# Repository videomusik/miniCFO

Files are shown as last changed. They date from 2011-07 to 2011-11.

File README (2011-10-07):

files for the miniCFO, the little brother to the CHEAP, FAT and OPEN project
===========================================================================
more info: http://8bitklubben.dk/project/CFO/2011/06/minicfo-at-roskilde-festival/
===========================================================================
in this repository you will find Arduino code to program the miniCFO synth (Arduino folder) and CAD files for the hardware design (Eagle folder). At the time being the version of the hardware design is the one made for a synthesizer workshop at Roskilde Festival 2011. A more generic design will be uploaded shortly.

sound code + hardware design in this project is based on the original CFO by Jacob Sikker Remin (https://github.com/jsr606/CFO) which is again based on the arduino synthesizer kit by critter and guittari (http://www.critterandguitari.com/content/arduino-synthesizer-kit)

PLEASE NOTE:
this is a work in progress: we encourage you to optimize/modify the hardware design and tweak the code! 

--- enjoy
          _____                    _____                   _______         
         /\    \                  /\    \                 /::\    \        
        /::\    \                /::\    \               /::::\    \       
       /::::\    \              /::::\    \             /::::::\    \      
      /::::::\    \            /::::::\    \           /::::::::\    \     
     /:::/\:::\    \          /:::/\:::\    \         /:::/~~\:::\    \    
    /:::/  \:::\    \        /:::/__\:::\    \       /:::/    \:::\    \   
   /:::/    \:::\    \      /::::\   \:::\    \     /:::/    / \:::\    \  
  /:::/    / \:::\    \    /::::::\   \:::\    \   /:::/____/   \:::\____\ 
 /:::/    /   \:::\    \  /:::/\:::\   \:::\    \ |:::|    |     |:::|    |
/:::/____/     \:::\____\/:::/  \:::\   \:::\____\|:::|____|     |:::|    |
\:::\    \      \::/    /\::/    \:::\   \::/    / \:::\    \   /:::/    / 
 \:::\    \      \/____/  \/____/ \:::\   \/____/   \:::\    \ /:::/    /  
  \:::\    \                       \:::\    \        \:::\    /:::/    /   
   \:::\    \                       \:::\____\        \:::\__/:::/    /    
    \:::\    \                       \::/    /         \::::::::/    /     
     \:::\    \                       \/____/           \::::::/    /      
      \:::\    \                                         \::::/    /       
       \:::\____\                                         \::/____/        
        \::/    /                                          ~~              
         \/____/

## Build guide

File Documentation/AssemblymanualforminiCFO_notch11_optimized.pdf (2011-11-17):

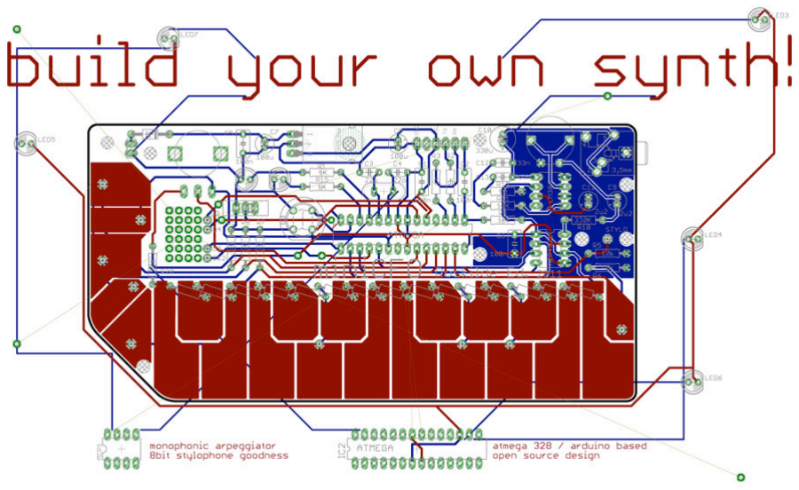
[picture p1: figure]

miniCFO assembly instructions ver1.1 ---- NOTCH11 workshop sept. 22nd 2011 more info: http://8bitklubben.dk/project/CFO/

0) This is the board when you get it. Check that all the components are in the bag!

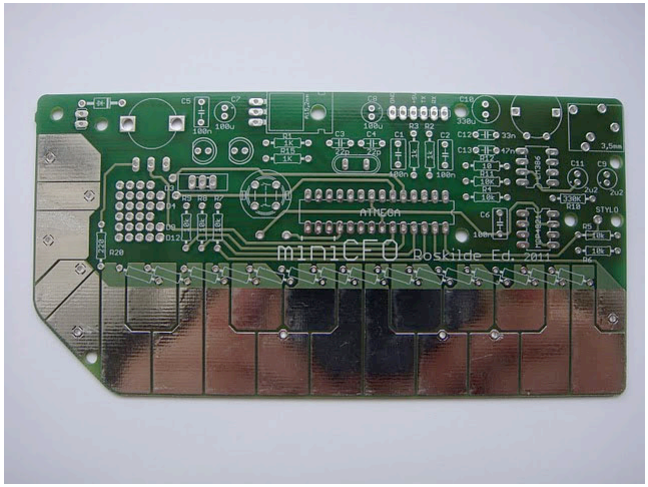
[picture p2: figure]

1) Solder the sixteen 220

Ω resistors near the Stylophone keys. Remember the last one on the far left (R20 that has written “220” in it)

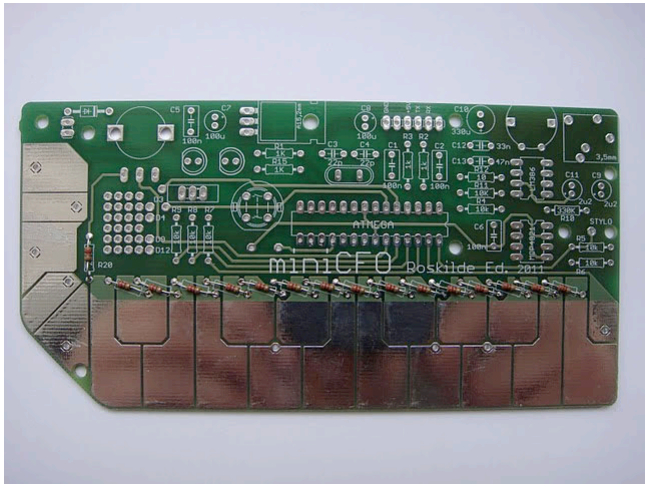
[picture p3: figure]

It can be easier to keep the resistors (and all following components) in place if you bend the legs on the backside of the board, before soldering. Just make sure not to get the legs too close to other soldering points. Snip o

ff the rest of the leg with a cutter when

finished
soldering. All soldering is on the backside, just in case you were in doubt :)

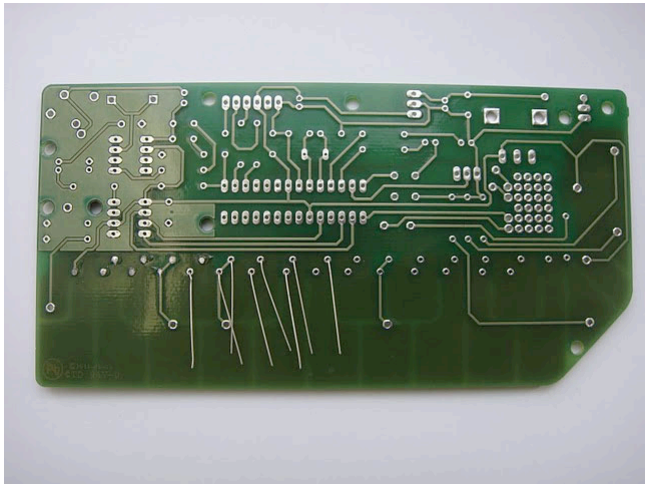
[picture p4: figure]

2) Solder the seven 10K

Ω resistors (R4, R5, R6, R7, R8, R9 and R11)

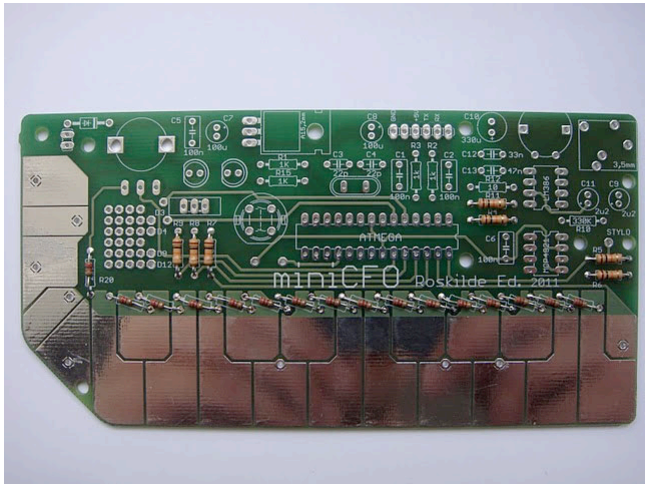
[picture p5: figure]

3) solder the four 1K

Ω resistors (R1, R15, R2 and R3)

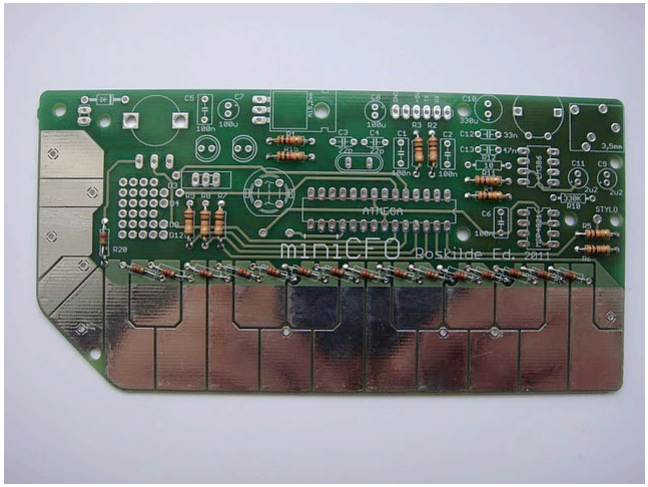
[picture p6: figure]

4) solder the 10

Ω and the 330K

Ω resistors (R12 and R10 respectively)

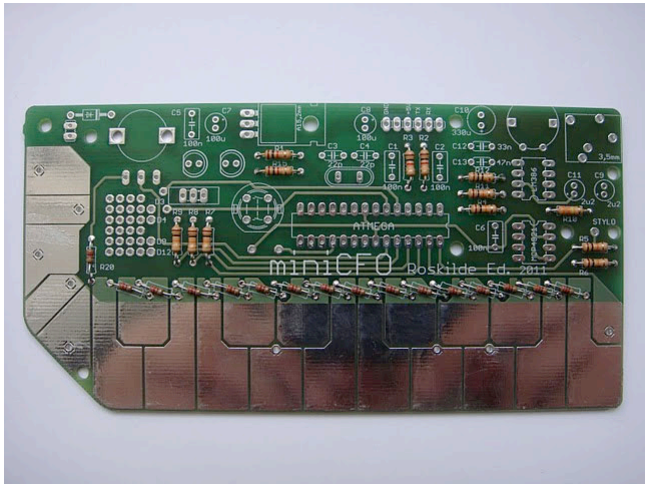
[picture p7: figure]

5) Solder the two 8 pin (MCP4921 and LM386) and the 28 pin (ATMEGA) IC sockets. Make sure that the little groove in one end of each socket lines up with the groove on the silkscreen (the drawings and text on the circuit board). Be aware that the the two 8 pin sockets have their groove pointing towards each other. We use these to help us position the microchips in the right direction later on.

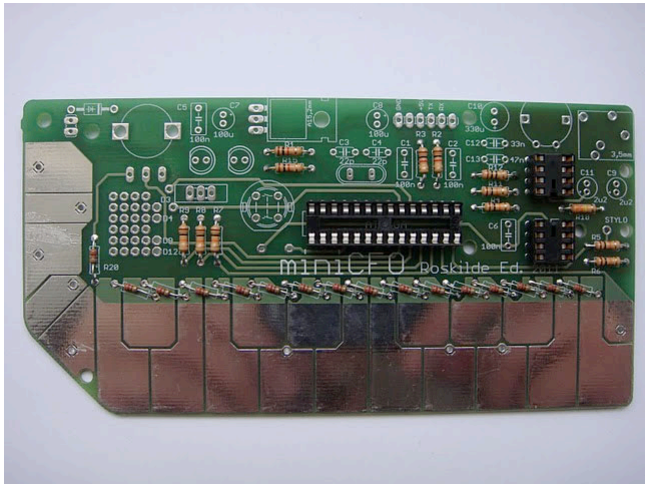
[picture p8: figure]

6) Solder the oscillator. It doesn’t have a direction, but it’s nice if the text

fits with all the rest :)

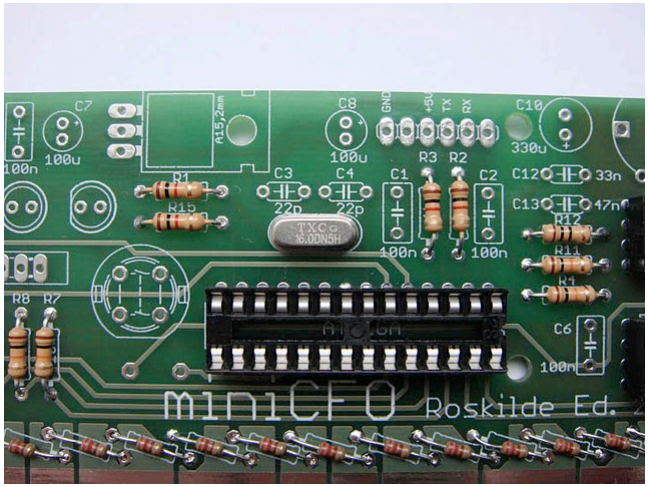
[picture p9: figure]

7) Solder the 6 pin, angled male header.

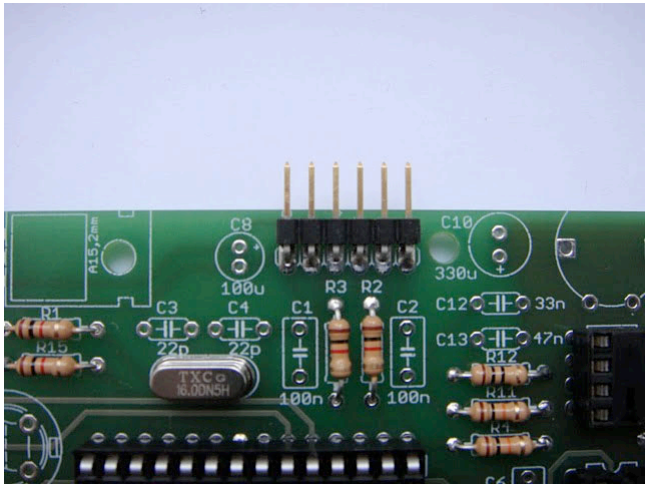
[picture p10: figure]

8) Solder the diode (1N4001). Watch the direction, make sure the white/grey end of the diode is to the right, where there is a white line on the silkscreen.

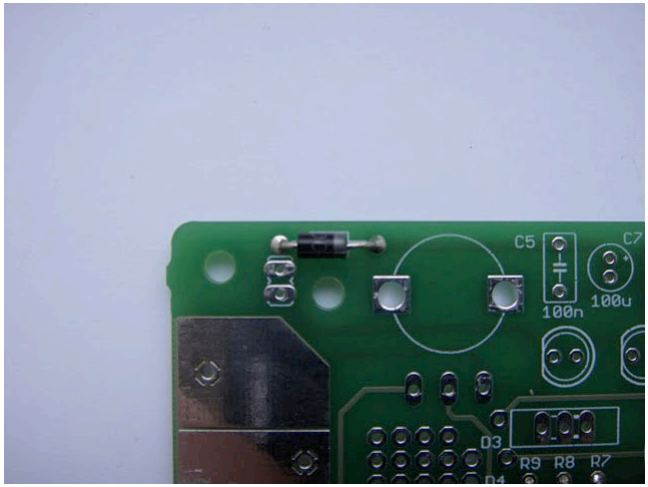
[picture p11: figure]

9) Solder the two 18pF capacitors (C3 and C4) above the oscillator. By a mistake there is written “22p” on the silkscreen, although the capacitors are 18pF.

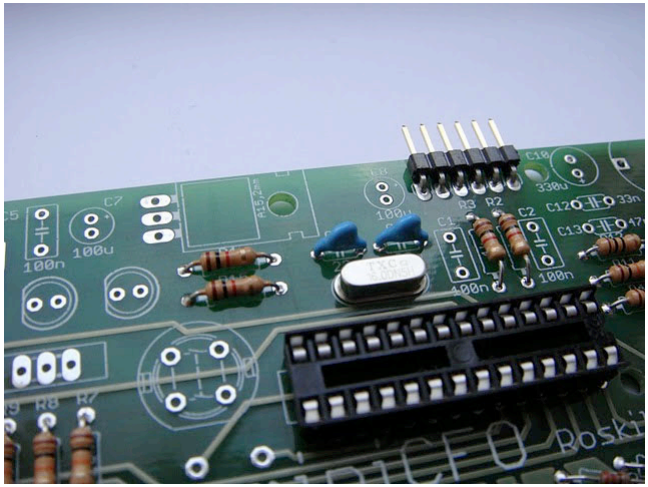
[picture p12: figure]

10) Solder the 33nF and 47nF capacitors (C12 and C13). The 47nF capacitor (C13) is the red one - you can’t miss it. The 33nF capacitor (C12) looks almost identical to the 100nF capacitors we will use in the next step. They are the same blue colour and have the same size. You should be able make out a small “33nJ63” on the proper 33nF one here, and a small “u1K63” on the 100nF ones.

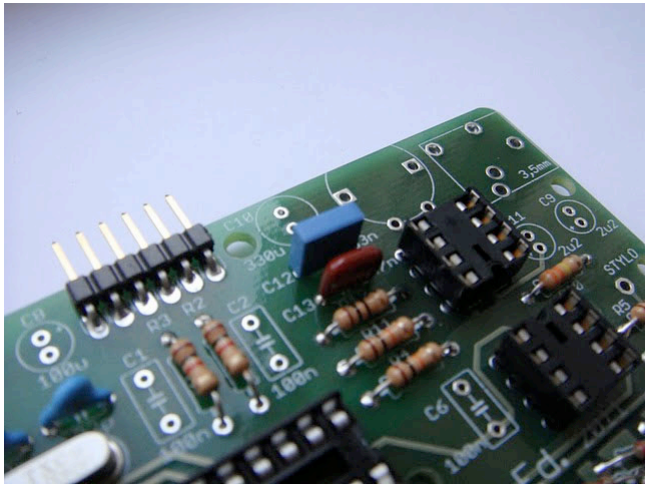
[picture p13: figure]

11) Solder the four 100nF capacitors (C1, C2, C5 and C6). As stated above, they are the blue ones that have a little “u1K63” written on them.

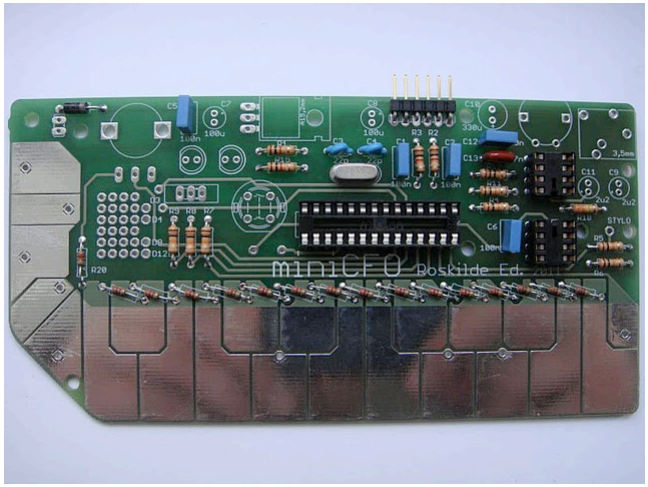
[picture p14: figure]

12) Solder the thumbwheel.

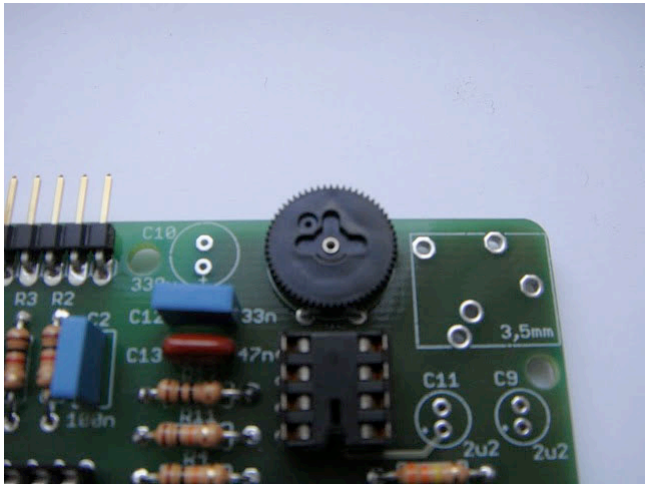
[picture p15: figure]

13) Solder the two LEDs. Watch the direction, make sure the short leg (the negative terminal) is facing left. You can also see it by the slightly

flattened side on the LED. This should be aligned with the

flat side on the silkscreen.

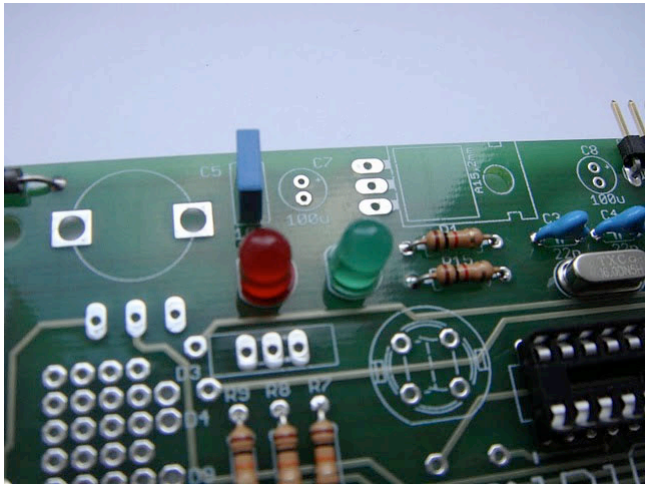
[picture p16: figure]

14) The next few steps are all on the same photo. First Solder the button (the big green thing). Watch the direction, there is a slightly flattened side on it (a little like the LED) which should be aligned with the

flat side on the silkscreen, facing down towards the “keyboard”.
15) Then solder the slider switch (the little black plastic thingy with the tip that slides from side to side :D). No special direction.
16) Lastly solder the 5V regulator. It’s the black thing with three legs and a metal top with a whole in it. Make sure it’s positioned like the photo.

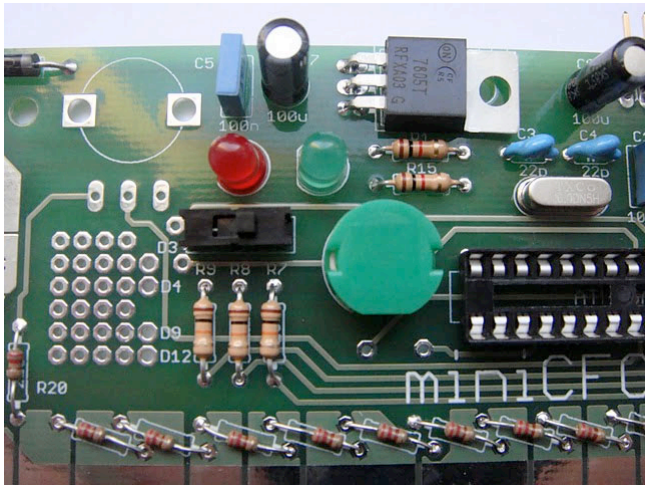
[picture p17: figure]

17) Solder the the electrolytic capacitors: two 2.2µF (C9 and C11), two 100µF (C7 and C8) and one 330µF (C10). Watch the direction, make sure the white line on each capacitor is facing AWAY from the little “+” (plus) on the silkscreen. That means the two 2.2µF capacitors (C9 and C11) and the 330µF (C10) are facing the white line upwards, AWAY from the “keyboard”. The other two (C7 and C8 at 100µF) face the white line downwards, TOWARDS the “keyboard”. It’s pretty important to get this right, because we otherwise may not get sound :)

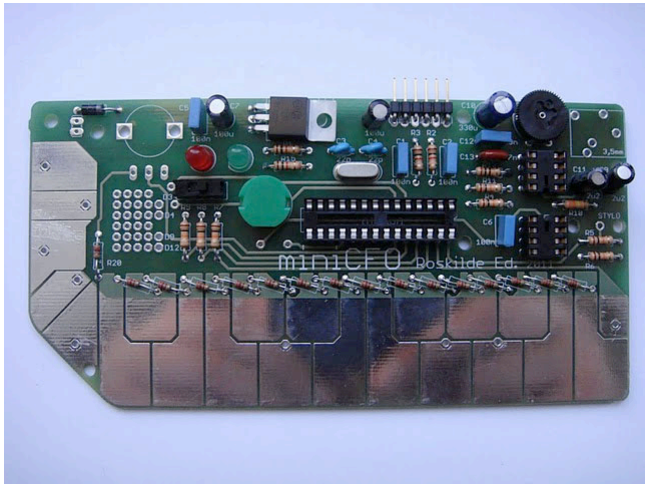
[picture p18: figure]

18) Solder the alligator stylo cable to the board. Pass the stylo cable through the hole from the backside and put the stripped wire into the solder pad under the S in “STYLO”. You can use the alligator tip of the cable to hold the cable into place when soldering. Make sure not to solder the tip to the board :) You can of course also pass the cable from above through the hole, and solder the stripped wire from the top side, if you feel like a true experimental interaction designer :D

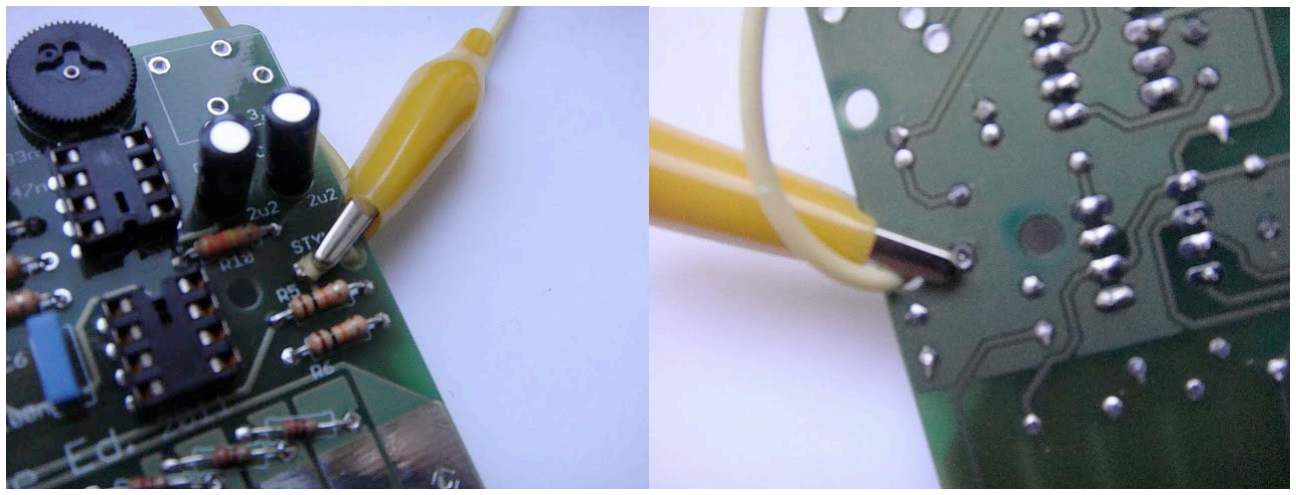
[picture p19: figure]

19) Solder the minijack socket. With the sockets we could get for the workshop at Roskilde, you have to cut one of the terminals (Hence the twisted position). Grab hold of one of us, so we can show you which one. The holes here are big, and we need a lot of solder, so don’t be afraid to

fill up the hole. It adds mechanical strength to resist the forces when you plug and unplug your minijacks.

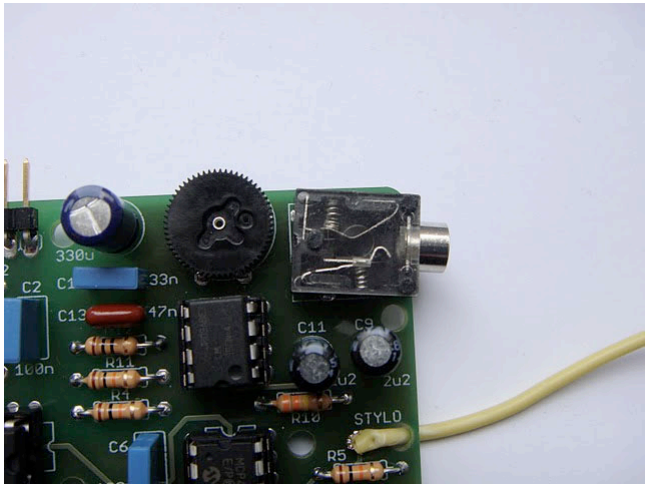
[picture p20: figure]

20) Solder the potentiometer. When the potentiometer has been clicked into place, grab a set of pliers and bend the “feet” up under the board. Make sure to also apply generous amounts of solder where the “feet” touches the solder pad (the “rim” of the hole), to add mechanical strength.

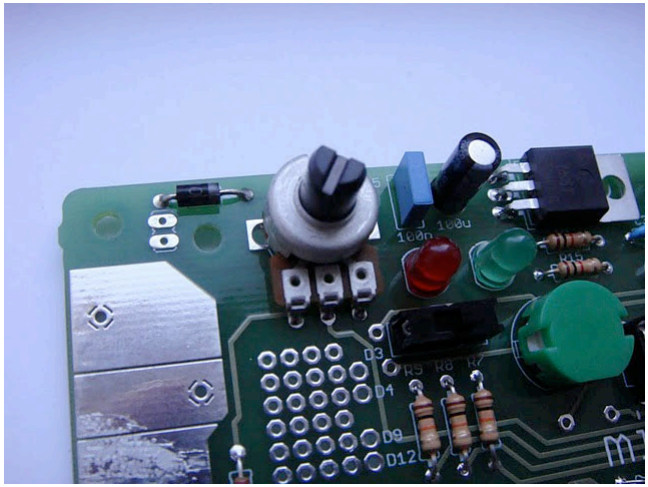
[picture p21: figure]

21) Solder the 9V battery plug cable in the same way as the stylo cable. Make sure the red cord goes to the solder pad closest to the diode.

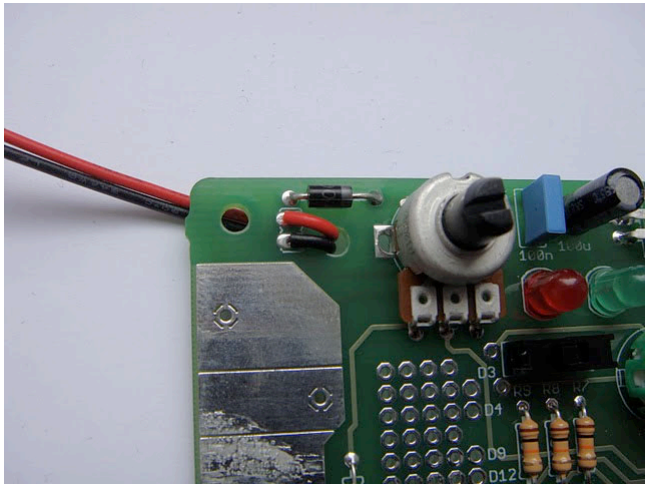
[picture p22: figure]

22) Put a knob on the potentiometer. We don’t have a photo of one, but you should be able to

figure it out. (Hint, it is the only part left!)

23) You are now done! Enjoy the look of your masterpiece, possibly make it pose for a few rockstar photos, before we start uploading code to see if it all actually works :D That part is a story for another tutorial.

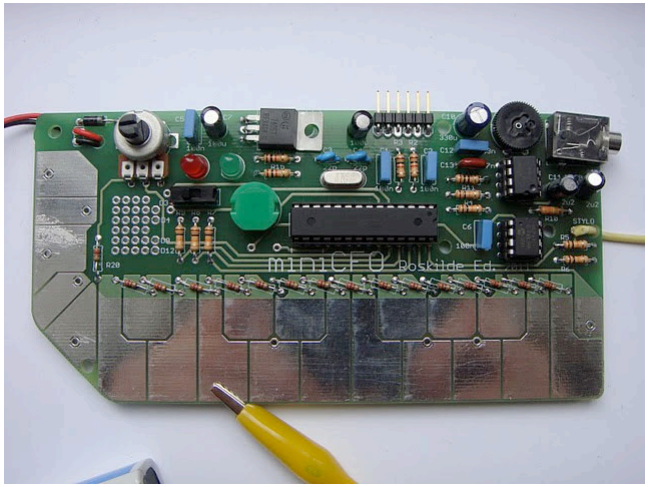
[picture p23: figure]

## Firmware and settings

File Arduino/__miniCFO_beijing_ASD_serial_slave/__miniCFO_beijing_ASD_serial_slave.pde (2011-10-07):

//          _____                    _____                   _______         
//         /\    \                  /\    \                 /::\    \        
//        /::\    \                /::\    \               /::::\    \       
//       /::::\    \              /::::\    \             /::::::\    \      
//      /::::::\    \            /::::::\    \           /::::::::\    \     
//     /:::/\:::\    \          /:::/\:::\    \         /:::/~~\:::\    \    
//    /:::/  \:::\    \        /:::/__\:::\    \       /:::/    \:::\    \   
//   /:::/    \:::\    \      /::::\   \:::\    \     /:::/    / \:::\    \  
//  /:::/    / \:::\    \    /::::::\   \:::\    \   /:::/____/   \:::\____\ 
// /:::/    /   \:::\    \  /:::/\:::\   \:::\    \ |:::|    |     |:::|    |
///:::/____/     \:::\____\/:::/  \:::\   \:::\____\|:::|____|     |:::|    |
//\:::\    \      \::/    /\::/    \:::\   \::/    / \:::\    \   /:::/    / 
// \:::\    \      \/____/  \/____/ \:::\   \/____/   \:::\    \ /:::/    /  
//  \:::\    \                       \:::\    \        \:::\    /:::/    /   
//   \:::\    \                       \:::\____\        \:::\__/:::/    /    
//    \:::\    \                       \::/    /         \::::::::/    /     
//     \:::\    \                       \/____/           \::::::/    /      
//      \:::\    \                                         \::::/    /       
//       \:::\____\                                         \::/____/        
//        \::/    /                                          ~~              
//         \/____/                              
  /* ++++++++++++++++++++++++++++++++++++++++++++++++++++++++++++++++++++++++++++++
   + miniCFO                                                                      +
   + part of the CHEAP, FAT and OPEN family                                       +
   + an open source platform for musical exploration, composition and performance +
   + by jakob bak + jacob sikker remin                                            +
   + roskilde edition 2011 --- code update for notch2011                          +
   + http://8bitklubben.dk/project/CFO/                                           +
   ++++++++++++++++++++++++++++++++++++++++++++++++++++++++++++++++++++++++++++++++
*/



#include <stdio.h>                      // lets us do some C string manipulations for the LCD display
#include <avr/pgmspace.h>               // lets us use progmem for the giant wavetables
#include <EEPROM.h>                     // lets us read from and write to the EEPROM

int frequency = 0;
int pitchBend;
int16_t gain = 0xff;                       // gain of oscillator
byte waveForm1 = 0;
byte waveForm2 = 0;
byte storeWav1 = waveForm1;
int oscMix = 0;
byte modulatorWaveForm = 0;
#define numberOfWaveforms 16
//waveforms available:
//"sine","square","pulse","triangle","sawtooth","fuzzsquare","digiwave 1","digiwave 2",
//"digiwave 3","digiwave 4","digiwave 5","digiwave 6",
//"tanwave 1","tanwave 2","tanwave 3","tanwave 4"

// FM synthesis
uint16_t harmonicity = 0;              // harmonicity (first 8 bits are fractional)
uint8_t modulatorDepth = 0;            // modulation depth (0 - 255)

// hertz values for each stylophone key
//int hertzTable[20] = {370,392,415,440,466,494,523,555,587,622,659,699,740,784,831,880,932,988,1047,1109};
int hertzTable[16] = {466,494,523,555,587,622,659,699,740,784,831,880,932,988,1047, 1109};
int octave = -1;                       //current base octave

// Slider switch
int slider = 0;

//stylophone input, through resistor ladder connected to analog input 5
//unsigned int styloVal[20] PROGMEM = {53, 101, 148, 193, 238, 282, 327, 372, 417, 462, 509, 557, 606, 657, 710, 765, 824, 886, 952, 1022};
unsigned int styloVal[16] PROGMEM = {60, 122, 180, 237, 295, 353, 412, 470, 529, 591, 654, 720, 789, 862, 940, 1023};
//noise threshold on analog input pins
#define styloNoise 50                  
#define oscSelectNoise 15
#define rightBodyswitchNoise 15

int activeKey = -1;
int oldActiveKey = activeKey;
boolean styloMapping = true;

// analog inputs defined as constants
#define STYLOPHONE_INPUT 5
#define BODYSWITCH_R 4
#define BODYSWITCH_LB 3
#define BODYSWITCH_LM 2
#define BODYSWITCH_LT 1
#define POTENTIOMETER 0

// digital inputs and outputs defined as constants 
#define LEFT_LED 5
#define RIGHT_LED 6
#define SLIDER_SWITCH 7
#define BUTTON 8

#define OSCMIX_FACTOR 0

//arpeggio
boolean arpOn = false;
int bpm = 120;
boolean looping = false;
uint32_t arpTime = 0;
uint32_t lastArpTime = 0;
uint32_t arpGate = 0;
uint32_t lastArpGate = 0;
float beatProgress = 0;
float lastBeatProgress = 0;
float decay = 0.75;
int arpIndex = 0;
float arpMultiplier = 1.0;
float arpMinor[] = {1.0,1.189, 1.498, 2.378};
float arpMajor[] = {1.0, 1.2599, 1.498, 2.5198};
boolean major = false;
boolean buttonPushed = false;

char feedback[33]; // 32 chars + line end

unsigned long lastFeedback = millis();
unsigned long lastNote, lastWaveform;
#define feedbackFrequency 500

unsigned long lastSequenceStep = millis();
int millisPerSequenceStep = 60000/bpm;

unsigned long lastButtonPush = millis();

#define buttonTime 500
#define waveSelectTime 500

//setup decay
int sustain = 100; //in ms
byte decaySteps = 1, decaySpeed = 4, endDecay = 0;
boolean decaying = false;
unsigned long lastDecay = millis();
byte startAttack = 255, endAttack = 255, attackSteps = 50, attackSpeed = 1;
boolean attacking = true;
unsigned long lastAttack = millis();

int highestNoise;

int lastPotRead;
#define potNoise 2

//tracker stuff
int memNoteStart = 0, memNoteEnd = 3, memNoteSubsteps = 4, memNotePos = 0, memCommandStart = 0, memCommandEnd = 3, memCommandSubsteps = 4, memCommandPos = 0;
int sequenceStart = 0, sequencePosition = sequenceStart, sequenceLength = 16, sequenceSubsteps = 4;
int memNoteLoops, memCommandLoops;
int millisPerNote, millisPerCommand;
unsigned long lastCommand;
int delayPerBeat = 100;
unsigned long killTime; // added to be able to kill notes -- not working very well -- OPTIMIZE
boolean kill = false;

// define serial (pseudo midi) commands
#define INSTRUMENT_CHANGE 128+73  //'I'
#define NOTE_SET 128+78           //'N'
#define KILL_NOTE 128+75          //'K'
#define GAIN_ABS 128+71           //'G'
#define GAIN_REL 128+103          //'g'
#define OCTAVE_ABS 128+79         //'O'
#define OCTAVE_REL 128+111        //'o'
#define WAVE 128+87               //'W'
#define TEMPO 128+66              //'B'


void setup()
{      
  Serial.begin(9600);                  // 2400 baud is max speed, since we are communicating via IR light on a 38kHz carrier frequency
  cli();                               // clear interrupts. this has been added, to get the pocket piano code working
  
  // arduino pocket piano code follows
  // more info on the pocket piano here: http://www.critterandguitari.com/home/store/arduino-piano.php
  // set up syntheziser
  // this is the timer 2 audio rate timer, fires an interrupt at 15625 Hz sampling rate
  
  TIMSK2 = 1<<OCIE2A;                      // interrupt enable audio timer
  OCR2A = 127;
  TCCR2A = 2;                              // CTC mode, counts up to 127 then resets
  TCCR2B = 0<<CS22 | 1<<CS21 | 0<<CS20;    // different for atmega8 (no 'B' i think)
  SPCR = 0x50;                             // set up SPI port
  SPSR = 0x01;
  DDRB |= 0x2E;                            // PB output for DAC CS, and SPI port
                                           // DAC SCK is digital 13, DAC MOSI is digital 11, DAC CS is digital 10
  PORTB |= (1<<2);                         // not exactly sure what this does. TO CHECK
   
  pinMode(LEFT_LED, OUTPUT);
  pinMode(RIGHT_LED, OUTPUT);
  
  pinMode(SLIDER_SWITCH, INPUT);
  digitalWrite(SLIDER_SWITCH, HIGH);    // sets internal pull-up resistor (20K), to pull

  pinMode(BUTTON, INPUT);
  digitalWrite(BUTTON, HIGH);           // sets internal pull-up resistor (20K), to pull
  
//  pinMode(9, OUTPUT);

  bitWrite(TCCR1A, COM1A0, 1);          // Toggle OC1A and OC1B on Compare Match.
  bitWrite(TCCR1A, COM1A1, 0);

  bitWrite(TCCR1B, CS10, 1);            // No prescaling
  bitWrite(TCCR1B, CS11, 0);                                                                                                                                                                                                                                                                                                                                                                                                                                                                                                                                                                                                                                                                                                                                                                                                                                                                                                                                                                                                                                                                                                                                                                                                                                                                                                                                                                                                                                                                                                                                                                                                                                                                                                                                                                                                                                                                                                                                                                                                                                                                                                                                                                                                                                                                                                                                                                                                                                                                                                                                                                                                                                                                                                                                                                                                                                                                                                                                                                                                                                                                                                                                                                      
  bitWrite(TCCR1B, CS12, 0);

  OCR1A = 210;
  OCR1B = 210;
  
  // global interrupt enable
  sei();     

  //we need this delay, otherwise the interrupts hang/mess up
  analogWrite(RIGHT_LED, 0); 
  analogWrite(LEFT_LED, 255); 
  delay(400);
  analogWrite(RIGHT_LED, 255); 
  analogWrite(LEFT_LED, 0); 
  delay(400);
  
  analogWrite(RIGHT_LED, 0); 
  analogWrite(LEFT_LED, 0); 
}

void loop() {
  
  //read expression control
  //bpm = getBPM();
  int expressionRead = getExpression();
  //sprintf(feedback, "expr: %d", expressionRead);  

  oscSelect();

  oscMix = getOscMix();
  
  pitchBend = expressionRead * 4;      // multiplication amount should be tweakable. NEW THING.
    
  slider = getSliderSwitch();
  checkButton();
  
  getBPM();  
  
  if (slider == 0) {
    if (buttonPushed) {
      //change octave
      changeOctave();
    }
    if (potChange) {
      int potRead = analogRead(POTENTIOMETER);
      if (potRead == 0) { // superfast decay
        decaySteps = 255;
      } else {
        decaySteps = 1;
      }
      if (potRead == 1023) { // neverending notes
        endDecay = endAttack;
      } else {
        endDecay = 0;  
      }
      decaySpeed = potRead/80;
      analogWrite(RIGHT_LED, potRead/4);
    }
  }
  
  if (Serial.available() >= 6) parseSerial();

  if (slider == 1 && !buttonPushed) {
    //go arpeggiator!
    //updateArpeggiator();
  }
  if (slider == 1 && buttonPushed) {
    //record arpeggio
  }
  
  stylophoneInput();

  volumeFilter();
  
  //updateArpeggiator();
  analogWrite(LEFT_LED, gain);

  attackSustainDecay();
  
  giveFeedback();
}

void volumeFilter() {
  int filter = analogRead(BODYSWITCH_R);
  if (filter > rightBodyswitchNoise) {
    filter = 255-constrain(filter,rightBodyswitchNoise,255);
    sprintf(feedback, "volume: %3d", filter);
    //if (filter > gain)
    gain = filter;  
  }
}

void changeOctave() {
    if (lastButtonPush+buttonTime < millis()) {
      octave++;
      if (octave == 3) octave = -3;
      lastButtonPush = millis();
    }
}

void giveFeedback() {
 if (lastFeedback + feedbackFrequency < millis()) {
//    Serial.println(feedback);
    lastFeedback = millis();
    highestNoise = 0;
  }
}

void attackSustainDecay() {
  
  // attack / sustain / decay hack
  
  if (attacking && (millis() > lastAttack + attackSpeed)) {
  //    sprintf(printMsg, "attacking: %3d", gain);
  //    printLCD(printMsg,1);  
    lastAttack = millis();
    if (gain < (endAttack-attackSteps)) {
      gain = gain + attackSteps;
    } else {
      gain = endAttack;
      attacking = false;
    }
    //sprintf(printMsg, "gain: %3d", gain);
    //printLCD(printMsg,1);  
  }
  
  
  // start decay when sustain is over
  if (millis() > lastNote + sustain) {
    decaying = true;
  }
  
  if (decaying && (millis() > lastDecay + decaySpeed)) {
  //    sprintf(printMsg, "decaying: %3d", gain);
  //    printLCD(printMsg,1); 
    lastDecay = millis();
    if (gain > (endDecay+decaySteps)) {
      gain = gain - decaySteps;
    } else {
      gain = endDecay;
      decaying = false;
    }
    //sprintf(printMsg, "gain: %3d", gain);
    //printLCD(printMsg,1);  
  }

}

void oscSelect() {
  int wavSelectR = analogRead(BODYSWITCH_LT);
  
//  highestNoise = max(wavSelectR,highestNoise);
//  sprintf(feedback, "oscSelect: %d", highestNoise);

  if (wavSelectR > oscSelectNoise && (millis() > (lastWaveform + waveSelectTime))) { 
    waveForm1 ++;
    waveForm1 = waveForm1 % numberOfWaveforms;
    sprintf(feedback, "new waveform: %d", waveForm1);
    lastWaveform = millis();
  }
}

void checkButton() {
  buttonPushed = !digitalRead(BUTTON);
}

int getSliderSwitch () { 
  return digitalRead(SLIDER_SWITCH);
}

int getOscMix () {
  int oscMix = analogRead(BODYSWITCH_LM) << OSCMIX_FACTOR;
  oscMix = constrain(oscMix,0,255);
  //sprintf(feedback, "oscMix: %d", oscMix);
  return oscMix;
}

int getBPM () {
  bpm = map(analogRead(POTENTIOMETER), 0, 1023, 0, 512);
  return bpm;
}

int getExpression () {
  return analogRead(BODYSWITCH_LB);
}

boolean getMajor() {
  int major = analogRead(BODYSWITCH_LT);
  if(major>4) return true;
  else return false;
}

void stylophoneInput () {
  //read stylophone input
  int styloRead = analogRead(STYLOPHONE_INPUT);
  highestNoise = max(styloRead,highestNoise);
  sprintf(feedback, "styloRead: %d", highestNoise);
  
  if (styloRead > styloNoise) {
    
    //sprintf(printMsg, "stylophone: %4d", styloRead);
    //printLCD (printMsg,0);    

    gain = startAttack;
    decaying = false;
    attacking = true;
    //sprintf(printMsg, "stylophone: %4d", styloRead);
    //printLCD (printMsg,0);    
    
    lastNote = millis();
    lastAttack = millis();
    
    if (styloMapping) {
      activeKey = stylophoneMapping (styloRead);
      //Serial.println(activeKey);
      //calculate frequency
      frequency = (int)((float)hertzTable[activeKey] * arpMultiplier * (float)pow(2,octave) + (float)pitchBend);
    } else {
      frequency = styloRead * pow(2,octave) + pitchBend;
    }
    
    if (activeKey != oldActiveKey) {
      oldActiveKey = activeKey;
    }
  } else {
    if(arpOn) {
      activeKey = oldActiveKey;
      frequency = (int)((float)hertzTable[activeKey] * arpMultiplier * (float)pow(2,octave) + (float)pitchBend);
    } else {
      activeKey = -1;
    }

  }  
}

boolean potChange() {
  int potRead = analogRead(POTENTIOMETER);
  if (potRead < lastPotRead - potNoise || potRead > lastPotRead + potNoise) {
    return true;
  } else {
    return false;
  }
}

int stylophoneMapping(int readVal){
  
  //Serial.print(readVal);
  //Serial.print("\t");
  
  int diff = 1023;
  int diffId = 0;

  for (int i = 0; i<20; i++) {
    if (abs(readVal - (int) pgm_read_word_near(&styloVal[i])) < diff) {
      diff = abs(readVal - (int) pgm_read_word_near(&styloVal[i]));
      diffId = i;
    }
  }
  return diffId;
}


void parseSerial() {

    int start = Serial.read();
    int address, note, octave_value, command, command_value;
    
    if (start == 130) {                // 128+2 = start of transmission
      analogWrite(RIGHT_LED, 255);
      address = Serial.read();
      note = Serial.read();
      octave_value = Serial.read();
      command = Serial.read();
      command_value = Serial.read();
      sprintf(feedback,"RX: %3d%3d%3d%3d",address,note,octave_value,command,command_value);

      trackerCommand(note,octave_value,command,command_value);
      lastNote = millis();
      analogWrite(RIGHT_LED,0);
    }
    
    if (start == 132) {                 // 128 + 4 = STX sequencer notes
      
      byte readNoteStart, readNoteLength, readNoteSubsteps, readNoteLoops;
      byte readCommandStart, readCommandLength, readCommandSubsteps, readCommandLoops;
      
      readCommandStart = Serial.read();
      readCommandLength = Serial.read();
      readCommandSubsteps = Serial.read();
      readCommandLoops = Serial.read();
      if (readCommandStart!=255) memCommandStart = readCommandStart;
      if (readCommandLength!=255) memCommandEnd = readCommandStart+readCommandLength;
      if (readCommandSubsteps!=255) memCommandSubsteps = readCommandSubsteps;
      if (readCommandLoops!=255) memCommandLoops = readCommandLoops;

      readNoteStart = Serial.read();
      readNoteLength = Serial.read();
      readNoteSubsteps = Serial.read();
      readNoteLoops = Serial.read();
      if (readNoteStart!=255) memNoteStart = readNoteStart;
      if (readNoteLength!=255) memNoteEnd = readNoteStart+readNoteLength;
      if (readNoteSubsteps!=255) memNoteSubsteps = readNoteSubsteps;
      if (readNoteLoops!=255) memNoteLoops = readNoteLoops;
        
      looping = true;
      
      memNotePos = memNoteStart;
      memCommandPos = memCommandStart;
      
      calculateDelays();
      
      lastNote = millis()-millisPerNote;
      lastCommand = millis()-millisPerCommand;
      
      //sprintf(printMsg,"mpn: %3d ",millisPerNote);
      //printLCD(printMsg,0);      
    }
    
    if (start == 133) { //tempo commands
      bpm = Serial.read();
      delayPerBeat = Serial.read()*4;
      Serial.read(); // start memory address notes
      Serial.read(); // end memory address notes
      Serial.read(); // start memory address commands
      Serial.read(); // end memory address commands
      
      if (bpm == 0) {
        looping = false;
      } else {
        looping = true;
        calculateDelays();
      }
    }
    Serial.flush();
}

void trackerCommand(int note, int octave_value, int command, int command_value) {

  if (command == KILL_NOTE) {
    if (command_value == 0) {
      gain = 0;
    } else {
      killTime = command_value + millis();
      kill = true;
    }
  }
   
  if (command == OCTAVE_REL) {
    octave += command_value-64;
    //sprintf(printMsg,"octave: %3d",octave);
    //printLCD(printMsg,0);
  }
  
  if (command == OCTAVE_ABS) {
    octave = command_value-64;
    //sprintf(printMsg,"octave: %3d",octave);
    //printLCD(printMsg,0);
  }

  if (command == GAIN_REL) {
    int result_gain = gain + (command_value-64);
    gain = constrain(result_gain,0,255);
    //sprintf(printMsg,"gain rel: %3d%3d",command_value-64,gain);
    //printLCD(printMsg,0);
  }
  
  if (command == GAIN_ABS) {
    gain = command_value*2;
    //sprintf(printMsg,"gain abs: %3d",gain);
    //printLCD(printMsg,0);
  }
  
  if (command == WAVE) {
    waveForm1 = command_value%numberOfWaveforms;
    //instrument = instrument%numberOfWaveforms;
  }
  
  if (command == TEMPO) {
    if (command_value == 0) command_value=1;
    bpm = map(command_value,1,255,1,1000);
    //millisPerSequenceStep = 60000/bpm/sequenceSubsteps;
    //sprintf(printMsg,"mps: %5d",millisPerSequenceStep);  
    //printLCD(printMsg,0);
  }
  
  if (note != 255 && octave_value != 255) {
    frequency = hertzTable[note] * pow(2,octave_value) * pow(2,octave);
    kill = false;

    gain = startAttack;
    decaying = false;
    attacking = true;
    //sprintf(printMsg, "stylophone: %4d", styloRead);
    //printLCD (printMsg,0);    
    
    lastNote = millis();
    lastAttack = millis();
    
  }
  if (note != 255 && octave_value == 255) {
    frequency = hertzTable[note] * pow(2,octave);
    kill = false;
    lastNote = millis();
    //gain = 255;
    //sprintf(printMsg,"note set: %3d %2d",note,octave);
    //printLCD(printMsg,0);
  }
  
  //Serial.flush();
}

void calculateDelays() {  
  //millisPerNote = 60000/bpm/memNoteSubsteps; //how many millis pr beat
  //millisPerCommand = 60000/bpm/memCommandSubsteps;
  millisPerNote = delayPerBeat;
  millisPerCommand = delayPerBeat;
  //sprintf(printMsg,"m%15d ",millisPerNote);
  //printLCD(printMsg,0);
}
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

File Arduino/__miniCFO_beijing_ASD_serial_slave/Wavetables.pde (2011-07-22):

/*********************************************
 * Plays Sine Tone on Arduino Pocket Piano
 * Author: Owen Osborn, Copyright: GPL 
 * 
 *  This uses Direct Digital Synthesis (DDS)  for tone generation
 *   
 * 5 October 2007
 *
 * FOR MCP4921 DAC
 *
 * Chip type           : ATMEGA168
 * Clock frequency     : 16MHz
 *********************************************/
/* hacked up with lots of wavetables in progmem by Josh Brandt, 6 October 2008 */


#define SPI_SCK 5
#define SPI_MOSI 3


prog_uint8_t waveTable[] PROGMEM ={
// sine
  0x80,0x83,0x86,0x89,0x8c,0x8f,0x92,0x95,0x98,0x9c,0x9f,0xa2,0xa5,0xa8,0xab,0xae,
  0xb0,0xb3,0xb6,0xb9,0xbc,0xbf,0xc1,0xc4,0xc7,0xc9,0xcc,0xce,0xd1,0xd3,0xd5,0xd8,
  0xda,0xdc,0xde,0xe0,0xe2,0xe4,0xe6,0xe8,0xea,0xec,0xed,0xef,0xf0,0xf2,0xf3,0xf5,
  0xf6,0xf7,0xf8,0xf9,0xfa,0xfb,0xfc,0xfc,0xfd,0xfe,0xfe,0xff,0xff,0xff,0xff,0xff,
  0xff,0xff,0xff,0xff,0xff,0xff,0xfe,0xfe,0xfd,0xfc,0xfc,0xfb,0xfa,0xf9,0xf8,0xf7,
  0xf6,0xf5,0xf3,0xf2,0xf0,0xef,0xed,0xec,0xea,0xe8,0xe6,0xe4,0xe2,0xe0,0xde,0xdc,
  0xda,0xd8,0xd5,0xd3,0xd1,0xce,0xcc,0xc9,0xc7,0xc4,0xc1,0xbf,0xbc,0xb9,0xb6,0xb3,
  0xb0,0xae,0xab,0xa8,0xa5,0xa2,0x9f,0x9c,0x98,0x95,0x92,0x8f,0x8c,0x89,0x86,0x83,
  0x80,0x7c,0x79,0x76,0x73,0x70,0x6d,0x6a,0x67,0x63,0x60,0x5d,0x5a,0x57,0x54,0x51,
  0x4f,0x4c,0x49,0x46,0x43,0x40,0x3e,0x3b,0x38,0x36,0x33,0x31,0x2e,0x2c,0x2a,0x27,
  0x25,0x23,0x21,0x1f,0x1d,0x1b,0x19,0x17,0x15,0x13,0x12,0x10,0x0f,0x0d,0x0c,0x0a,
  0x09,0x08,0x07,0x06,0x05,0x04,0x03,0x03,0x02,0x01,0x01,0x00,0x00,0x00,0x00,0x00,
  0x00,0x00,0x00,0x00,0x00,0x00,0x01,0x01,0x02,0x03,0x03,0x04,0x05,0x06,0x07,0x08,
  0x09,0x0a,0x0c,0x0d,0x0f,0x10,0x12,0x13,0x15,0x17,0x19,0x1b,0x1d,0x1f,0x21,0x23,
  0x25,0x27,0x2a,0x2c,0x2e,0x31,0x33,0x36,0x38,0x3b,0x3e,0x40,0x43,0x46,0x49,0x4c,
  0x4f,0x51,0x54,0x57,0x5a,0x5d,0x60,0x63,0x67,0x6a,0x6d,0x70,0x73,0x76,0x79,0x7c,
// square

  0xff,0xff,0xff,0xff,0xff,0xff,0xff,0xff,0xff,0xff,0xff,0xff,0xff,0xff,0xff,0xff,
  0xff,0xff,0xff,0xff,0xff,0xff,0xff,0xff,0xff,0xff,0xff,0xff,0xff,0xff,0xff,0xff,
  0xff,0xff,0xff,0xff,0xff,0xff,0xff,0xff,0xff,0xff,0xff,0xff,0xff,0xff,0xff,0xff,
  0xff,0xff,0xff,0xff,0xff,0xff,0xff,0xff,0xff,0xff,0xff,0xff,0xff,0xff,0xff,0xff,
  0xff,0xff,0xff,0xff,0xff,0xff,0xff,0xff,0xff,0xff,0xff,0xff,0xff,0xff,0xff,0xff,
  0xff,0xff,0xff,0xff,0xff,0xff,0xff,0xff,0xff,0xff,0xff,0xff,0xff,0xff,0xff,0xff,
  0xff,0xff,0xff,0xff,0xff,0xff,0xff,0xff,0xff,0xff,0xff,0xff,0xff,0xff,0xff,0xff,
  0xff,0xff,0xff,0xff,0xff,0xff,0xff,0xff,0xff,0xff,0xff,0xff,0xff,0xff,0xff,0xff,
  0x00,0x00,0x00,0x00,0x00,0x00,0x00,0x00,0x00,0x00,0x00,0x00,0x00,0x00,0x00,0x00,
  0x00,0x00,0x00,0x00,0x00,0x00,0x00,0x00,0x00,0x00,0x00,0x00,0x00,0x00,0x00,0x00,
  0x00,0x00,0x00,0x00,0x00,0x00,0x00,0x00,0x00,0x00,0x00,0x00,0x00,0x00,0x00,0x00,
  0x00,0x00,0x00,0x00,0x00,0x00,0x00,0x00,0x00,0x00,0x00,0x00,0x00,0x00,0x00,0x00,
  0x00,0x00,0x00,0x00,0x00,0x00,0x00,0x00,0x00,0x00,0x00,0x00,0x00,0x00,0x00,0x00,
  0x00,0x00,0x00,0x00,0x00,0x00,0x00,0x00,0x00,0x00,0x00,0x00,0x00,0x00,0x00,0x00,
  0x00,0x00,0x00,0x00,0x00,0x00,0x00,0x00,0x00,0x00,0x00,0x00,0x00,0x00,0x00,0x00,
  0x00,0x00,0x00,0x00,0x00,0x00,0x00,0x00,0x00,0x00,0x00,0x00,0x00,0x00,0x00,0x00,
  
// pulse
  0x00,0x00,0x00,0x00,0x00,0x00,0x00,0x00,0x00,0x00,0x00,0x00,0x00,0x00,0x00,0x00,
  0x00,0x00,0x00,0x00,0x00,0x00,0x00,0x00,0x00,0x00,0x00,0x00,0x00,0x00,0x00,0x00,
  0x00,0x00,0x00,0x00,0x00,0x00,0x00,0x00,0x00,0x00,0x00,0x00,0x00,0x00,0x00,0x00,
  0x00,0x00,0x00,0x00,0x00,0x00,0x00,0x00,0x00,0x00,0x00,0x00,0x00,0x00,0x00,0x00,
  0x00,0x00,0x00,0x00,0x00,0x00,0x00,0x00,0x00,0x00,0x00,0x00,0x00,0x00,0x00,0x00,
  0x00,0x00,0x00,0x00,0x00,0x00,0x00,0x00,0x00,0x00,0x00,0x00,0x00,0x00,0x00,0x00,
  0x00,0x00,0x00,0x00,0x00,0x00,0x00,0x00,0x00,0x00,0x00,0x00,0x00,0x00,0x00,0x00,
  0x00,0x00,0x00,0x00,0x00,0x00,0x00,0x00,0x00,0x00,0x00,0x00,0x00,0x00,0x00,0x00,
  0x00,0x00,0x00,0x00,0x00,0x00,0x00,0x00,0x00,0x00,0x00,0x00,0x00,0x00,0x00,0x00,
  0x00,0x00,0x00,0x00,0x00,0x00,0x00,0x00,0x00,0x00,0x00,0x00,0x00,0x00,0x00,0x00,
  0x00,0x00,0x00,0x00,0x00,0x00,0x00,0x00,0x00,0x00,0x00,0x00,0x00,0x00,0x00,0x00,
  0x00,0x00,0x00,0x00,0x00,0x00,0x00,0x00,0x00,0x00,0x00,0x00,0x00,0x00,0x00,0x00,
  0x00,0x00,0x00,0x00,0x00,0x00,0x00,0x00,0x00,0x00,0x00,0x00,0x00,0x00,0x00,0x00,
  0xff,0xff,0xff,0xff,0xff,0xff,0xff,0xff,0xff,0xff,0xff,0xff,0xff,0xff,0xff,0xff,
  0xff,0xff,0xff,0xff,0xff,0xff,0xff,0xff,0xff,0xff,0xff,0xff,0xff,0xff,0xff,0xff,
  0xff,0xff,0xff,0xff,0xff,0xff,0xff,0xff,0xff,0xff,0xff,0xff,0xff,0xff,0xff,0xff,
//triangle
0x00,0x02,0x04,0x06,0x08,0x0a,0x0c,0x0e,0x10,0x12,0x14,0x16,0x18,0x1a,0x1c,0x1e,
0x20,0x22,0x24,0x26,0x28,0x2a,0x2c,0x2e,0x30,0x32,0x34,0x36,0x38,0x3a,0x3c,0x3e,
0x40,0x42,0x44,0x46,0x48,0x4a,0x4c,0x4e,0x50,0x52,0x54,0x56,0x58,0x5a,0x5c,0x5e,
0x60,0x62,0x64,0x66,0x68,0x6a,0x6c,0x6e,0x70,0x72,0x74,0x76,0x78,0x7a,0x7c,0x7e,
0x80,0x82,0x84,0x86,0x88,0x8a,0x8c,0x8e,0x90,0x92,0x94,0x96,0x98,0x9a,0x9c,0x9e,
0xa0,0xa2,0xa4,0xa6,0xa8,0xaa,0xac,0xae,0xb0,0xb2,0xb4,0xb6,0xb8,0xba,0xbc,0xbe,
0xc0,0xc2,0xc4,0xc6,0xc8,0xca,0xcc,0xce,0xd0,0xd2,0xd4,0xd6,0xd8,0xda,0xdc,0xde,
0xe0,0xe2,0xe4,0xe6,0xe8,0xea,0xec,0xee,0xf0,0xf2,0xf4,0xf6,0xf8,0xfa,0xfc,0xfe,
0xff,0xfd,0xfb,0xf9,0xf7,0xf5,0xf3,0xf1,0xef,0xed,0xeb,0xe9,0xe7,0xe5,0xe3,0xe1,
0xdf,0xdd,0xdb,0xd9,0xd7,0xd5,0xd3,0xd1,0xcf,0xcd,0xcb,0xc9,0xc7,0xc5,0xc3,0xc1,
0xbf,0xbd,0xbb,0xb9,0xb7,0xb5,0xb3,0xb1,0xaf,0xad,0xab,0xa9,0xa7,0xa5,0xa3,0xa1,
0x9f,0x9d,0x9b,0x99,0x97,0x95,0x93,0x91,0x8f,0x8d,0x8b,0x89,0x87,0x85,0x83,0x81,
0x7f,0x7d,0x7b,0x79,0x77,0x75,0x73,0x71,0x6f,0x6d,0x6b,0x69,0x67,0x65,0x63,0x61,
0x5f,0x5d,0x5b,0x59,0x57,0x55,0x53,0x51,0x4f,0x4d,0x4b,0x49,0x47,0x45,0x43,0x41,
0x3f,0x3d,0x3b,0x39,0x37,0x35,0x33,0x31,0x2f,0x2d,0x2b,0x29,0x27,0x25,0x23,0x21,
0x1f,0x1d,0x1b,0x19,0x17,0x15,0x13,0x11,0x0f,0x0d,0x0b,0x09,0x07,0x05,0x03,0x01,
// sawtooth
0xff,0xfe,0xfd,0xfc,0xfb,0xfa,0xf9,0xf8,0xf7,0xf6,0xf5,0xf4,0xf3,0xf2,0xf1,0xf0,
0xef,0xee,0xed,0xec,0xeb,0xea,0xe9,0xe8,0xe7,0xe6,0xe5,0xe4,0xe3,0xe2,0xe1,0xe0,
0xdf,0xde,0xdd,0xdc,0xdb,0xda,0xd9,0xd8,0xd7,0xd6,0xd5,0xd4,0xd3,0xd2,0xd1,0xd0,
0xcf,0xce,0xcd,0xcc,0xcb,0xca,0xc9,0xc8,0xc7,0xc6,0xc5,0xc4,0xc3,0xc2,0xc1,0xc0,
0xbf,0xbe,0xbd,0xbc,0xbb,0xba,0xb9,0xb8,0xb7,0xb6,0xb5,0xb4,0xb3,0xb2,0xb1,0xb0,
0xaf,0xae,0xad,0xac,0xab,0xaa,0xa9,0xa8,0xa7,0xa6,0xa5,0xa4,0xa3,0xa2,0xa1,0xa0,
0x9f,0x9e,0x9d,0x9c,0x9b,0x9a,0x99,0x98,0x97,0x96,0x95,0x94,0x93,0x92,0x91,0x90,
0x8f,0x8e,0x8d,0x8c,0x8b,0x8a,0x89,0x88,0x87,0x86,0x85,0x84,0x83,0x82,0x81,0x80,
0x7f,0x7e,0x7d,0x7c,0x7b,0x7a,0x79,0x78,0x77,0x76,0x75,0x74,0x73,0x72,0x71,0x70,
0x6f,0x6e,0x6d,0x6c,0x6b,0x6a,0x69,0x68,0x67,0x66,0x65,0x64,0x63,0x62,0x61,0x60,
0x5f,0x5e,0x5d,0x5c,0x5b,0x5a,0x59,0x58,0x57,0x56,0x55,0x54,0x53,0x52,0x51,0x50,
0x4f,0x4e,0x4d,0x4c,0x4b,0x4a,0x49,0x48,0x47,0x46,0x45,0x44,0x43,0x42,0x41,0x40,
0x3f,0x3e,0x3d,0x3c,0x3b,0x3a,0x39,0x38,0x37,0x36,0x35,0x34,0x33,0x32,0x31,0x30,
0x2f,0x2e,0x2d,0x2c,0x2b,0x2a,0x29,0x28,0x27,0x26,0x25,0x24,0x23,0x22,0x21,0x20,
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

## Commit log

2011-07-22 upload Arduino files
2011-07-22 Upload Eagle Files
    [miniCFO-roskilde.brd, miniCFO-roskilde.sch]
2011-07-27 moved Arduino files to individual directories for each version of the code
2011-11-17 added assembly instructions as .pdf
